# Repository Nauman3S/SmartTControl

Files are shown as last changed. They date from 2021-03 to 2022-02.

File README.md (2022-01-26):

<p align="center">
  <a href="" rel="noopener">
 Project logo</a>
</p>

<h3 align="center">SmartTControl</h3>

<div align="center">

[]()

</div>

---

<p align="center"> SmartTControl ESP32 Firmware and Python based Backend
    <br> 
</p>

## 📝 Table of Contents

- [About](#about)
- [Getting Started](#getting_started)
- [Circuit](#circuit)
- [Server Details](#server)
- [MQTT Topic Details](#mqtt)
- [API Details](#api)
- [Usage](#usage)
- [List Of Components](#list)
- [Built Using](#built_using)
- [Authors](#authors)

## 🧐 About 

This repo contains

- Backend
- Firmware
- Client auto-Installer script
- Detailed instructions

for SmartT Controller.

## Getting Started 

These instructions will get you a copy of the project up and running on your system.

### Prerequisites

Things you need to install the FW.

```
- Arduino IDE
```

### Installing 

A step by step series that tell you how to get the Firmware and Backend running

#### ESP32 Configuration

You should have Arduino IDE Installed

1.  Add ESP32 Board to your Arduino IDE
1.  In your Arduino IDE, go to File> Preferences
    Installing ESP32 Add-on in Arduino IDE Windows, Mac OS X, Linux open preferences
1.  Enter `https://dl.espressif.com/dl/package_esp32_index.json`
    into the “Additional Board Manager URLs” field then, click the “OK” button:
    Note: if you already have the ESP32 boards URL, you can separate the URLs with a comma(each board will go to neaw line) as follows:
    `https://dl.espressif.com/dl/package_esp32_index.json,\n http://arduino.esp8266.com/stable/package_esp8266com_index.json`

1.  Open the Boards Manager. Go to Tools > Board > Boards Manager…
1.  Search for ESP32 and press install button for the ESP32 by Espressif Systems“:
1.  That’s it. It should be installed after a few seconds.
1.  In your Arduino sketchbook directory, create tools directory if it doesn't exist yet.
1.  Unpack the tool into tools directory(present in libs/ESP32FS-1.0.zip) (the path will look like <home_dir>/Arduino/tools/ESP32FS/tool/esp32fs.jar).
1.  Close and re-open the Arduino IDE.

1.  Now copy the contents of the libs folder to the libraries directory of your Arduino
    1. If you are using windows, the libraries directory will be Documents/Arduino/libraries

##### ESP32 Node FW Uploading

1.  Select ESP32 Dev Module from Tools->Board->ESP32
2.  Select the correct port from Tools->Port
3.  Then open Firmware.ino file,
4.  Select Tools > ESP32 Sketch Data Upload menu item. This should start uploading the files into ESP32 flash file system.
5.  Now Upload the Code to your ESP32 Dev Module.
6.  Your ESP32 is now ready to be used.

## Circuit 
### Circuit Diagram

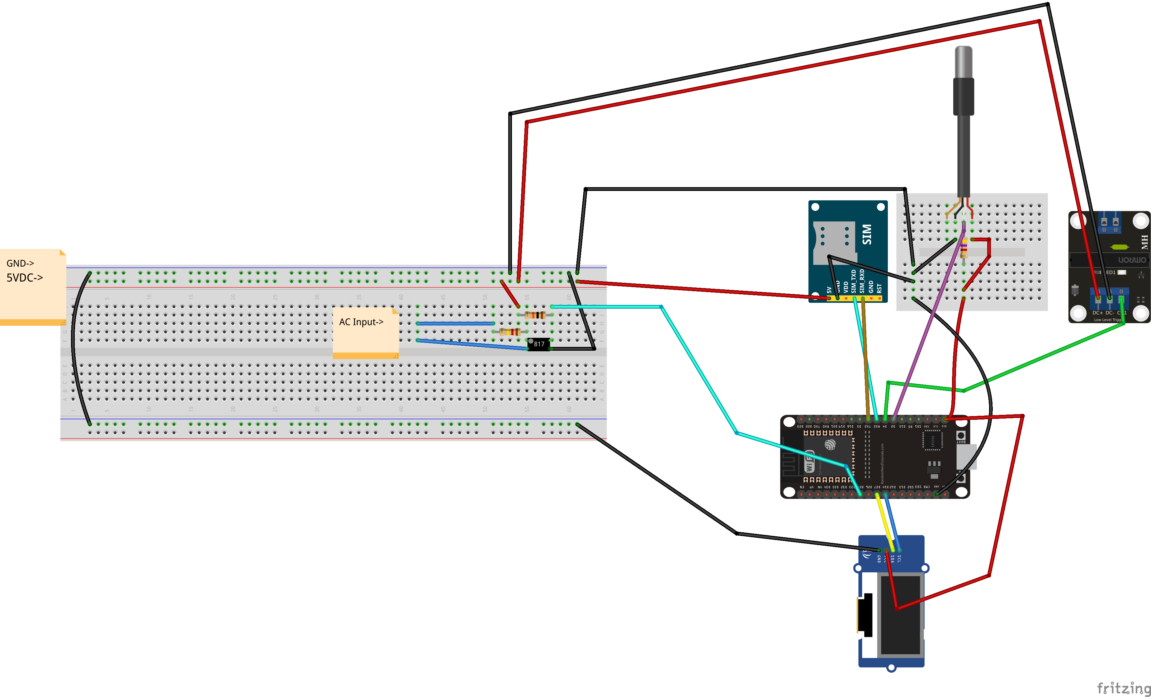
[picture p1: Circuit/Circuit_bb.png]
Circuit


### PCB

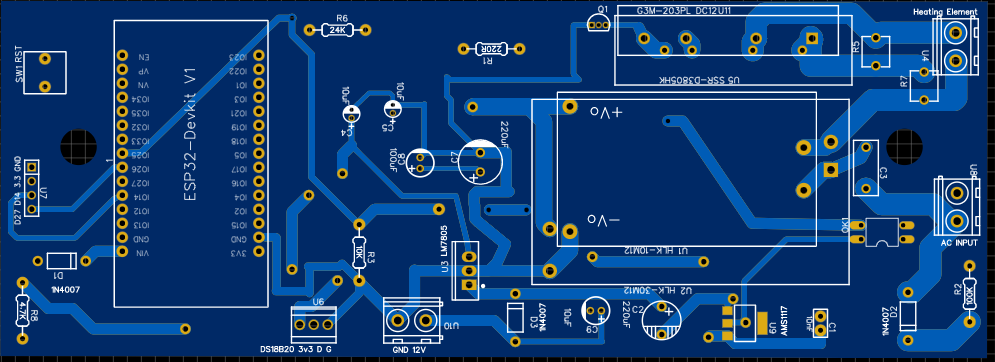
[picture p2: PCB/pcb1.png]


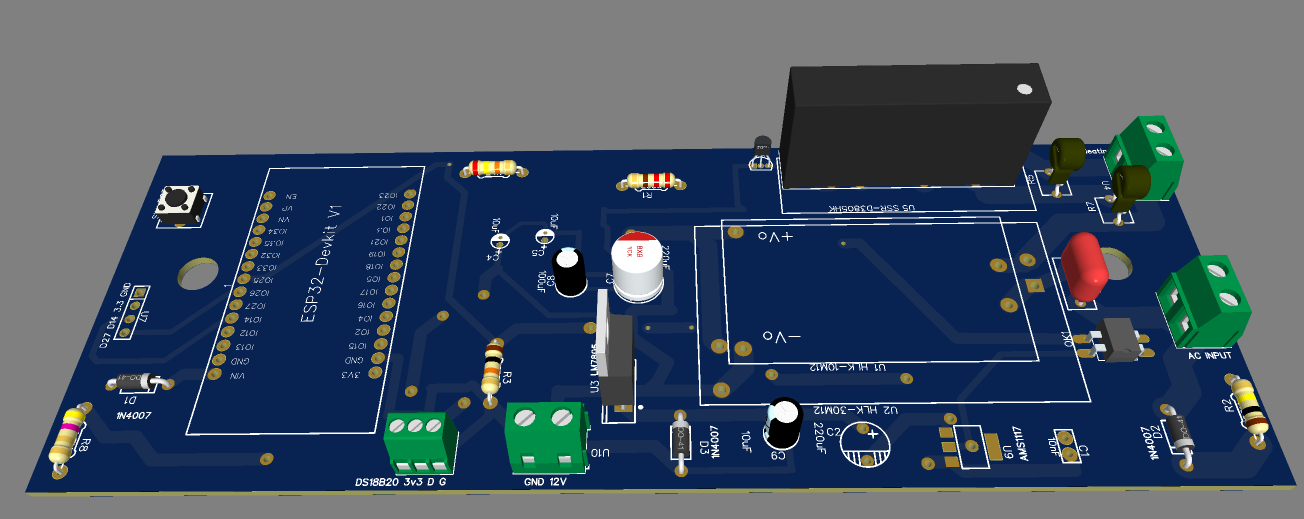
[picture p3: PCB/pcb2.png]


## Server Details 

* This Section was used for WebScrapper based implementation of SmartTControl
### Monitoring

- CapRover

### List of Packages installed on server

- Mosquitto Broker
- NodeJS, NPM, Node, NVM
- PM2
- ufw
- Caprover
- Docker
- mongod
- mongo-express

### Version Details

- Node v12.16.1
- NPM v6.13.4

## API Details 

### Live Sensor Nodes

```http
GET http://cmots.ca:8081/api/checkProductInfo
```

| Parameter | Type | Description |
| :--- | :--- | :--- |
| `imei` | `string` | IMEI of the device |
| `email` | `string` | email address of the cmots account |

-   Returns the data of live sensor in the format below.
```JSON
{
      "status": true,
      "userImeiProductData":
        {
        "Temperature": "15.70",
        "Humidity": "-1000.00",
        "Pressure": "-1000.00",
        "Battery": "-1000.00",
        "ServerTime": "2021-01-06 17:27:24.000"
    }
}
```
### Responses

The CMOTS can return the following responses
- user email not matched  
```javascript
{
    "status": false,
    "message": "User Not Found"
}
```
- device imei not matched  
```javascript
{
"status": false,
"message": "Product Not Found"
}

```

The `message` attribute contains a message commonly used to indicate errors or to return the logged status/

The `status` attribute describes if the transaction was successful or not.

## Usage 

1.  Upload the code to your ESP32.
2. Power on your ESP32, it will present you with an AP named `cmots-abc` (while `cmots` can be changed in the portal and `abc` is a unique id for each esp32)
3. Default captive portal password `12345678` which can be changed in captive portal. 
4. Connect to the ESP32 access point and open the web-browser and navigate to the link `http://cmots.local/_ac`. This link will work on most of the operating systems but if your operating system is not allowing to open it, you may want to check the captive portal IP Address from the serial monitor and can use that IP address inplace of the above mentioned URL. 
5. The default access IP Address is `http://192.168.4.1/_ac` 
6. You will be presented with a main dashboard as shown below(based on your device)
7.  Once connected to a WiFi network, you can again access the captive portal using same URL or the IP Address from the Serial monitor.
8.   You can open settings page with following default credentials
     1.  User: **cmots**
     2.  Password: **admin**

## ⛏️ Built Using 

- [Python](https://www.python.org/) - Backend and Scrapper
- [C++](https://isocpp.org/) - Firmware
- [ESP32-Arduino-Core](https://github.com/espressif/arduino-esp32) - Arduino Core for ESP32
- [Arduino](arduino.cc/) - Arduino Environment

## ✍️ Authors 

- [@Nauman3S](https://github.com/Nauman3S) -  Initial work

<!-- See also the list of [contributors](https://github.com/kylelobo/The-Documentation-Compendium/contributors) who participated in this project.

## 🎉 Acknowledgements 

- Hat tip to anyone whose code was used
- Inspiration
- References -->

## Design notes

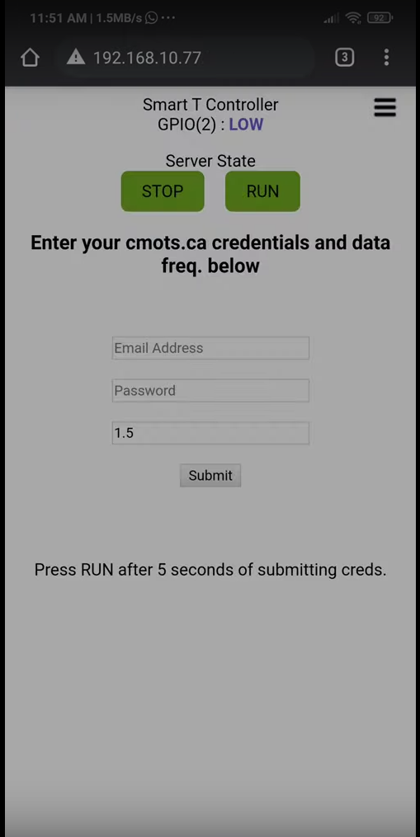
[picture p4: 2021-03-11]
artwork/scr.png

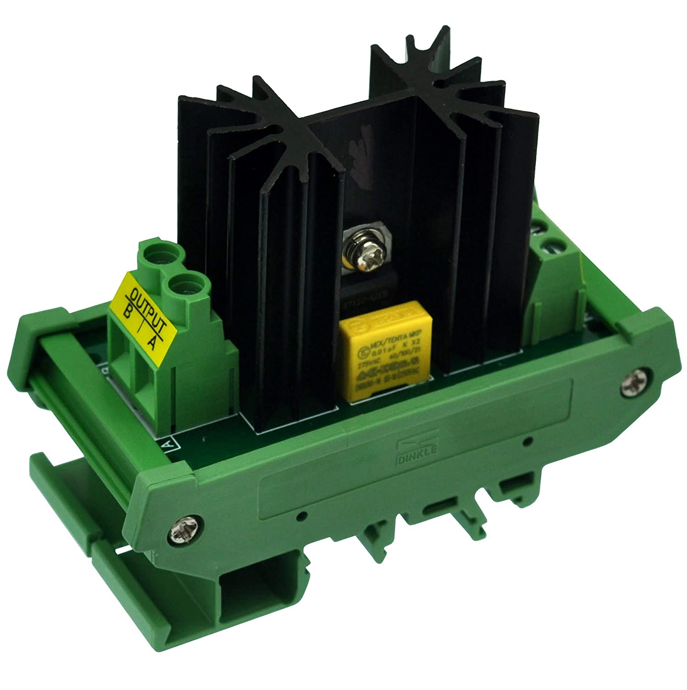
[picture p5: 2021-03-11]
artwork/ssr.jpg

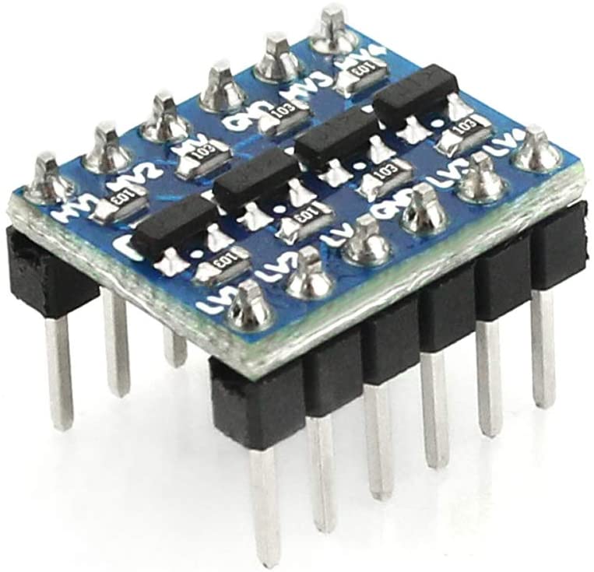
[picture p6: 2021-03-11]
artwork/levelShifter.jpg

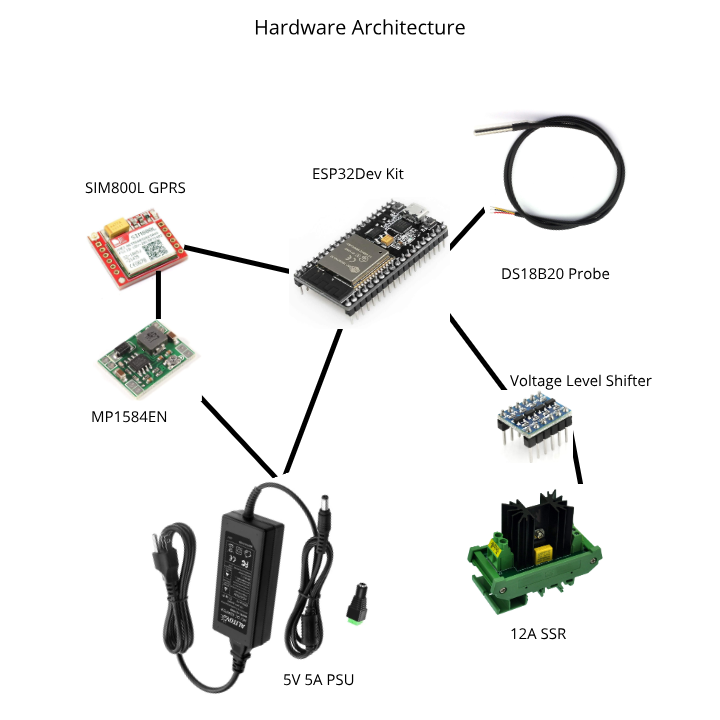
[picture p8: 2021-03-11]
artwork/HWArch.png

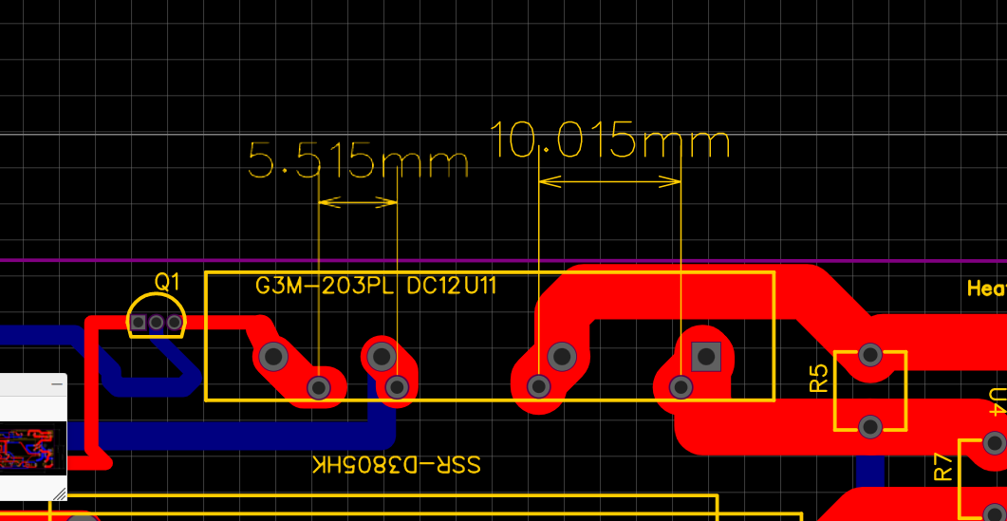
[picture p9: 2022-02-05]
PCB/dims.png

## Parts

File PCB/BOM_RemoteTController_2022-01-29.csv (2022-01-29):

ID | Name | Designator | Footprint | Quantity | Manufacturer Part | Manufacturer | Supplier | Supplier Part | Price | Pins | EasyEDA | JLCPCB Part Class | Contributor | JLCPCB Part Class | Tolerance | Value | Voltage | image | link
1 | ESP32DEVKITV1 | 1 | ESP32-DEVKITV1 | 1 |  |  |  |  |  | 30 |  |  | Baiel Muzuraimov
2 | 10nF | C1 | 10NF | 1 | 103Z-50V | EasyEDA | EasyEDA | E3758 |  | 2 | E3758 |  | erwin.lau |  | -20% | 10nF | 50V
3 | 220uF | C2 | CAP 220UF 16V 5X5 MM. | 1 | 220uF 16V 10*17 | LCSC | LCSC | C43827 | 0.057 | 2 |  |  |  |  |  | 220uF | 16V
4 | 100nF | C3 | CAP-TH_L10.0-W4.5-P7.50-D1.0 | 1 | 104 250v CBBCapacitor | ReliaPro | LCSC | C21820 |  | 2
5 | 10uF | C4,C5 | CAP-D3.0XF1.5 | 2 | 10uF 16V 3*5 | ValuePro | LCSC | C43798 | 0.019 | 2 |  |  |  |  |  | 10uF | 16V
6 | 220uF | C7 | CAP-TH_BD8.0-P3.50-D1.0-FD | 1 | 220uf/35V | ValuePro | LCSC | C2063 | 0.036 | 2 |  |  |  | Extended Part
7 | 100uF | C8 | CAP-TH_BD5.0-P2.00-D0.8-FD | 1 | 100uf/10V | ValuePro | LCSC | C2035 | 0.011 | 2 |  |  |  | Extended Part
8 | 10uF | C9 | CAP-TH_BD5.0-P2.00-D0.8-FD | 1 | 10uF 16V 5*11 | ValuePro | LCSC | C43799 | 0.013 | 2 |  | Extended Part |  | Extended Part
9 | 1N4007RLG | D1,D2,D3 | DO-41_BD2.4-L4.7-P8.70-D0.9-RD | 3 | 1N4007RLG | ON | LCSC | C53568 | 0.064 | 2 |  | Extended Part |  |  |  |  |  | //image.lceda.cn/szlcsc/C53568.jpg
10 | PC817 | OK1 | DIL04 | 1 |  |  |  |  |  | 4 |  |  | abialet
11 | 2N2222A facile for souder | Q1 | 2N2222A | 1 | 2N2222A |  | LCSC |  |  | 3 |  |  | HURARD
12 | 220_R_1/2W | R1 | 220 RESISTOR 1/2W | 1 |  |  |  |  |  | 2 |  |  | jokosays
13 | 100k_R_1/2W | R2 | 100K RESISTOR 1/2W | 1 |  |  |  |  |  | 2 |  |  | jokosays
14 | 10k_R_1/2W | R3 | 10K RESISTOR 1/2W | 1 |  |  |  |  |  | 2 |  |  | jokosays
15 | 101KD05J | R5,R7 | RES-TH_L5.5-W5.0-P5.00-D0.6 | 2 | 101KD05J | Brightking Elec (TAIWAN) | LCSC | C522112 | 0.061 | 2 |  |  | LCSC
16 | 24K_R_1/2W | R6 | 24K RESISTOR 1/2W | 1 |  |  |  |  |  | 2 |  |  | jokosays
17 | 4.7K_R_1/2W | R8 | 4.7 RESISTOR 1/2W | 1 |  |  |  |  |  | 2 |  |  | jokosays
18 | Push Button - 6x6mm - 2 pins | SW1 | PUSH BUTTON | 1 | Push button |  |  |  |  | 2 |  |  | JoseQuintanilla
19 | Hi-Link Power Module | U1 | HLK-10M12 | 1 | HLK-10M12 | HI-LINK | LCSC | C403746 | 5.193 | 4 |  |  | jorgePerez |  |  |  |  |  | https://lcsc.com/product-detail/Power-Modules_HI-LINK-HLK-10M12_C403746.html
20 | HLK-30M12 | U2 | PWRM-TH_HLK-30MXX | 1 | HLK-30M12 | HI-LINK(海凌科) | LCSC | C2761166 | 11.189 | 4 |  | Extended Part | LCSC
21 | LM7805CT | U3 | TO-220-3_L10.0-W4.5-P2.54-L | 1 | LM7805CT | FAIRCHILD | LCSC | C22146 |  | 3
22 | YC0220500000G | U4,U8,U10 | CONN-TH_YC0220500000G | 3 | YC0220500000G | Amphenol | LCSC | C2683165 | 0.646 | 2 |  |  | LCSC
23 | SSR-D3805HK | U5 | SSR-D3805HK | 1 | SSR-D3805HK |  | LCSC | SSR-D3805HK |  | 4 |  |  | Luis Alejandro Hernández Somaza
24 | VN03A1500000G | U6 | CONN-TH_VN03A1500000G | 1 | VN03A1500000G | Amphenol | LCSC | C2683164 | 1.097 | 3 |  |  | LCSC
25 | OLED | U7 | HEADER_PRG_1X04 | 1 |  |  |  |  |  | 4 |  |  | Bert62
26 | AMS1117 | U9 | AMS1117 | 1 |  |  | Amish | HLK-PM01 |  | 3 |  |  | Gremlinware
27 | G3M-203PL DC12 | U11 | RELAY-TH_G3M-203P-DC12 | 1 | G3M-203PL DC12 | OMRON(欧姆龙) | LCSC | C1559423 | 31.848 | 4 |  |  | LCSC

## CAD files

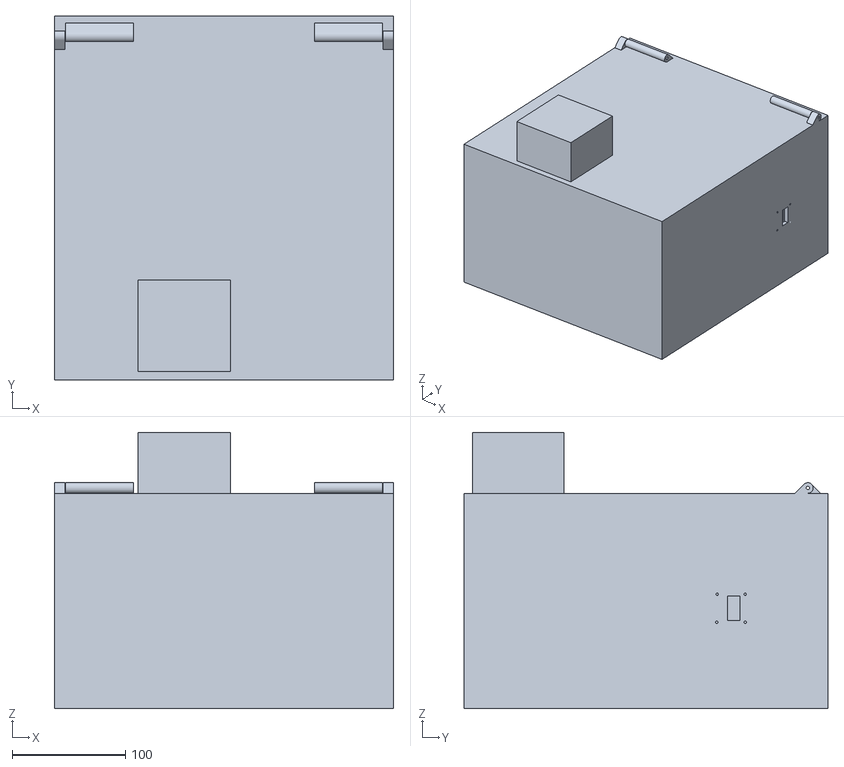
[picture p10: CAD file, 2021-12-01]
Casing/SmartTController v43.stl
300.0 x 321.8 x 244.0

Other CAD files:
Casing/SmartTController v43.f3d

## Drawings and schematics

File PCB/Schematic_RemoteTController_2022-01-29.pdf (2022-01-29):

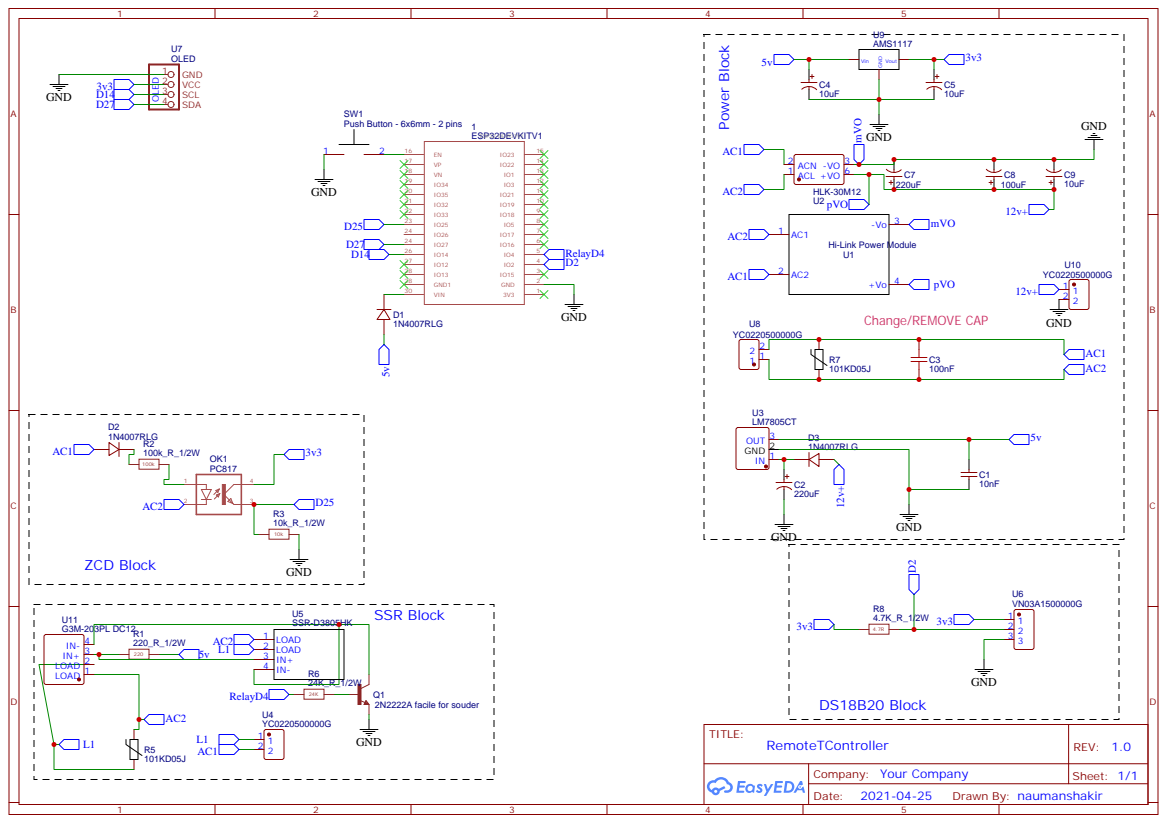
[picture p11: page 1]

Hi-Link Power Module

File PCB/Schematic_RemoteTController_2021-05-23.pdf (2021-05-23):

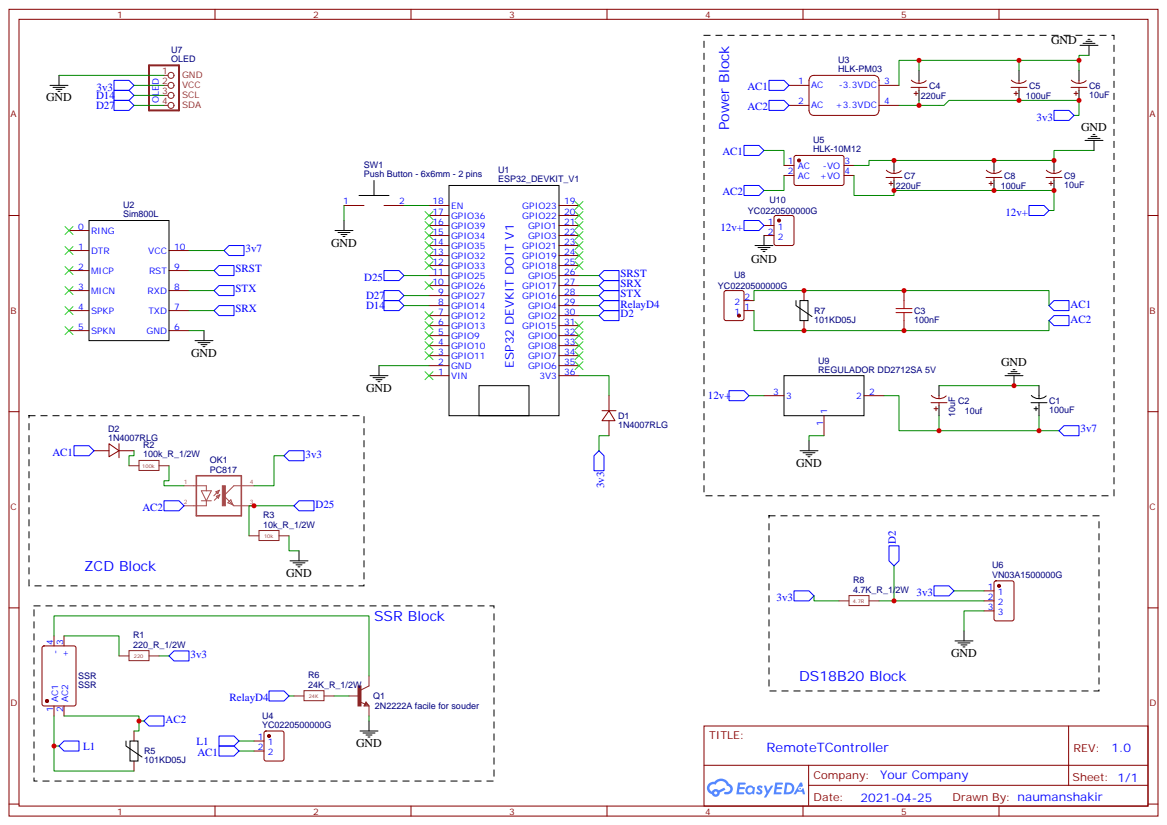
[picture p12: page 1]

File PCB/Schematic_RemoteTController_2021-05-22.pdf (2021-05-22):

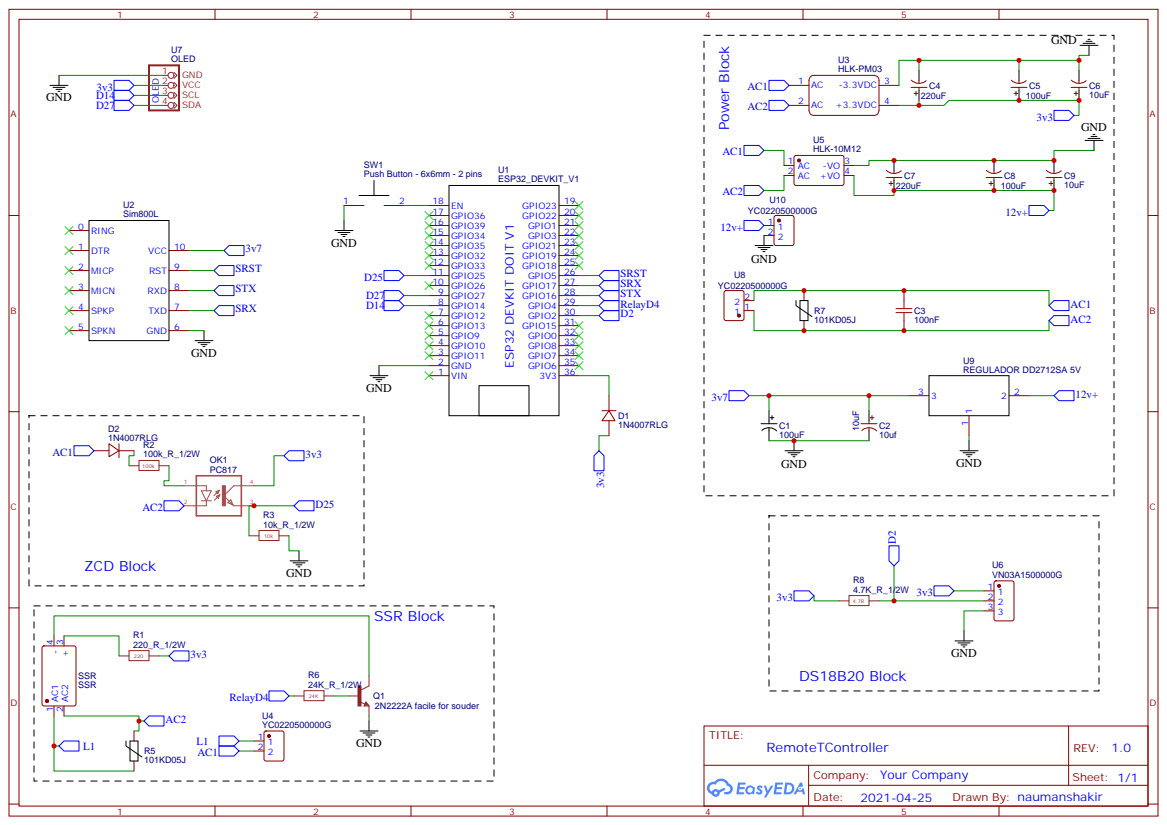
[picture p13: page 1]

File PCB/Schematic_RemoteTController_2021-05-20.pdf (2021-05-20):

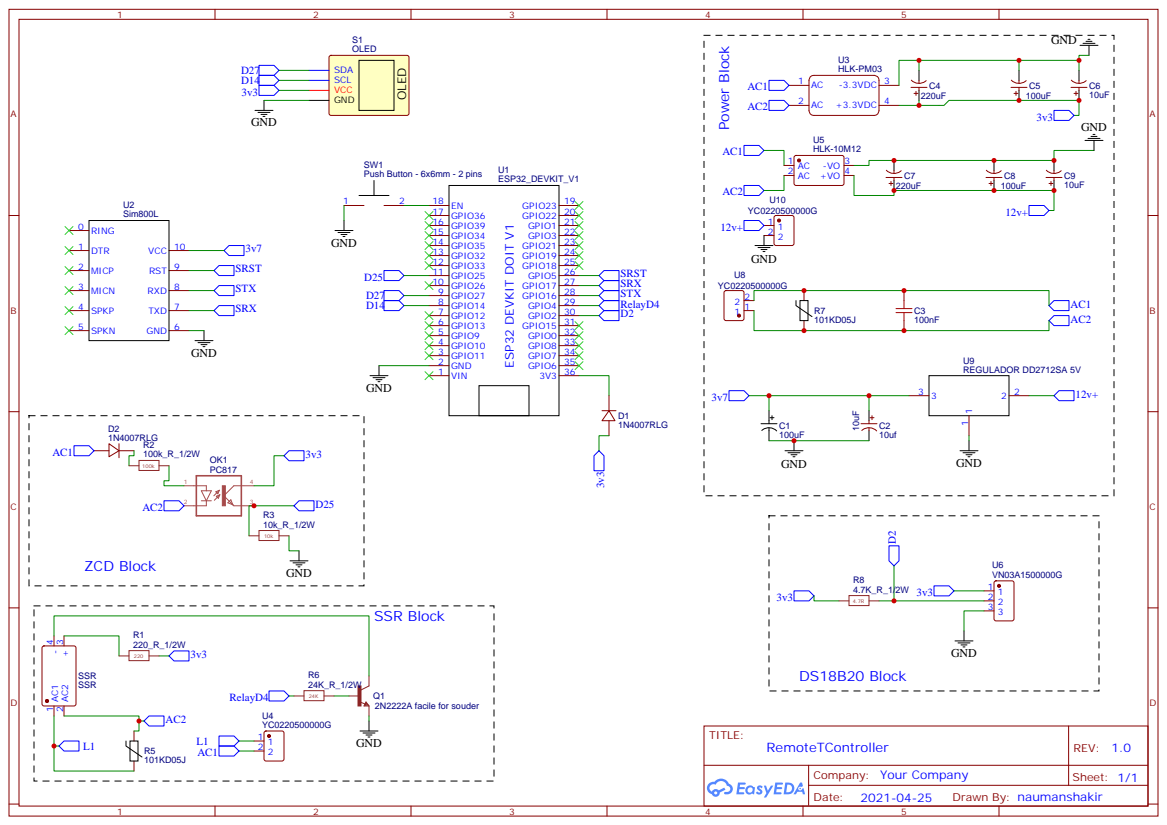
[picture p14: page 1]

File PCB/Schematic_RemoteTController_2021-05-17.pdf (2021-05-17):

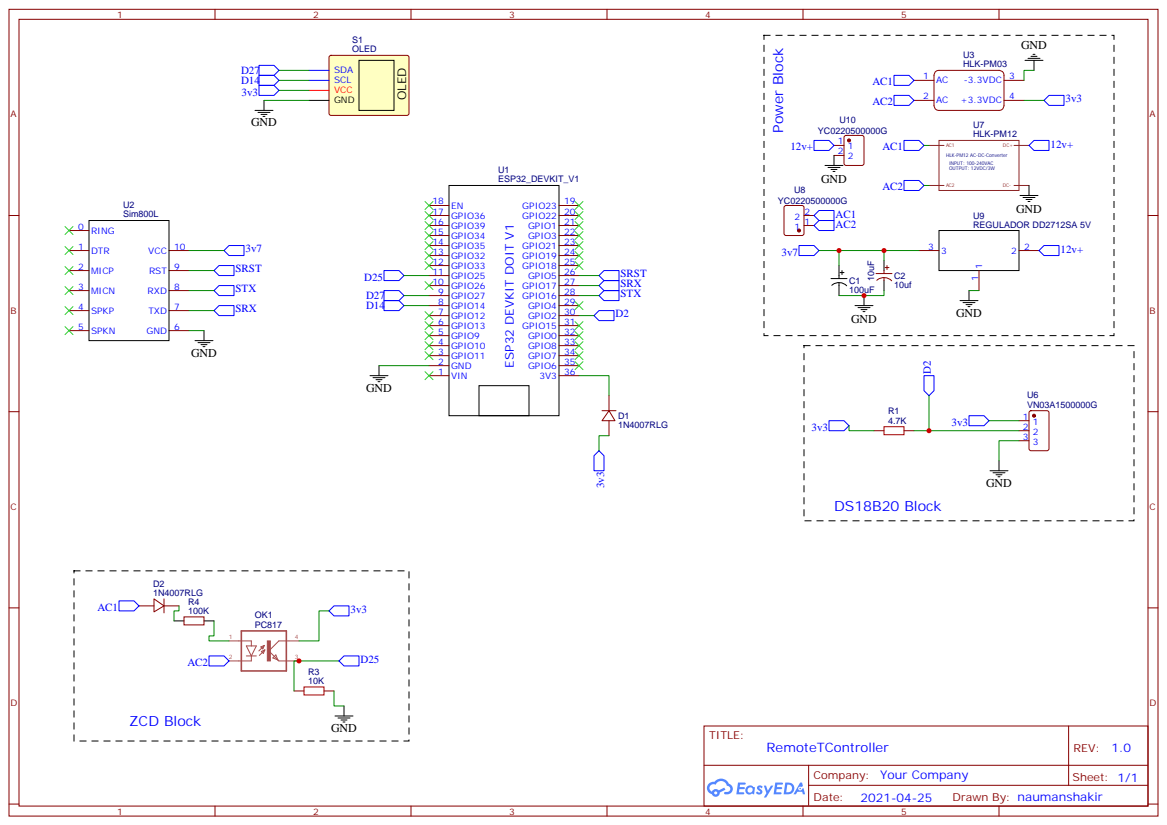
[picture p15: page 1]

HLK-PM12 AC-DC-Converter
INPUT: 100-240VAC
OUTPUT: 12VDC/3W

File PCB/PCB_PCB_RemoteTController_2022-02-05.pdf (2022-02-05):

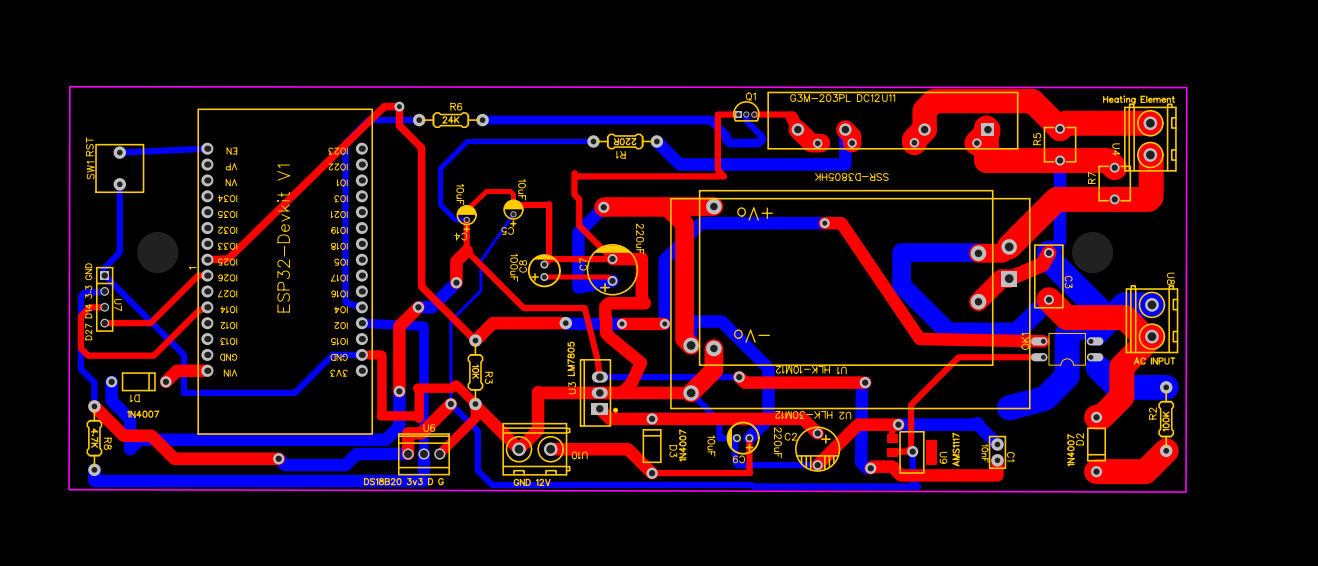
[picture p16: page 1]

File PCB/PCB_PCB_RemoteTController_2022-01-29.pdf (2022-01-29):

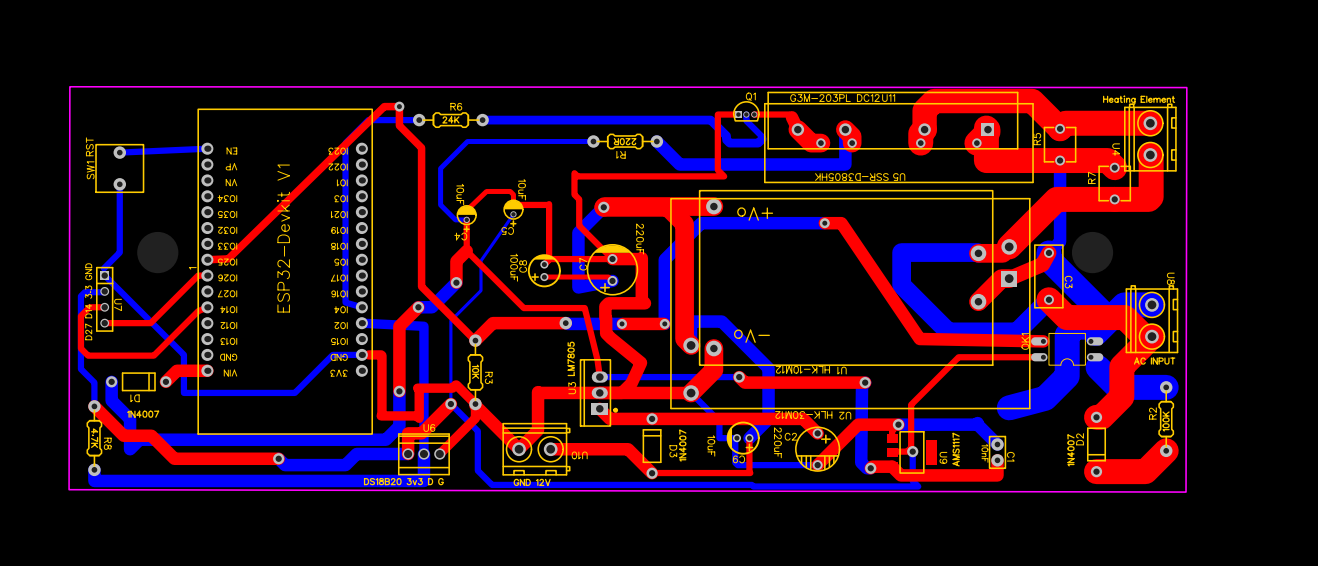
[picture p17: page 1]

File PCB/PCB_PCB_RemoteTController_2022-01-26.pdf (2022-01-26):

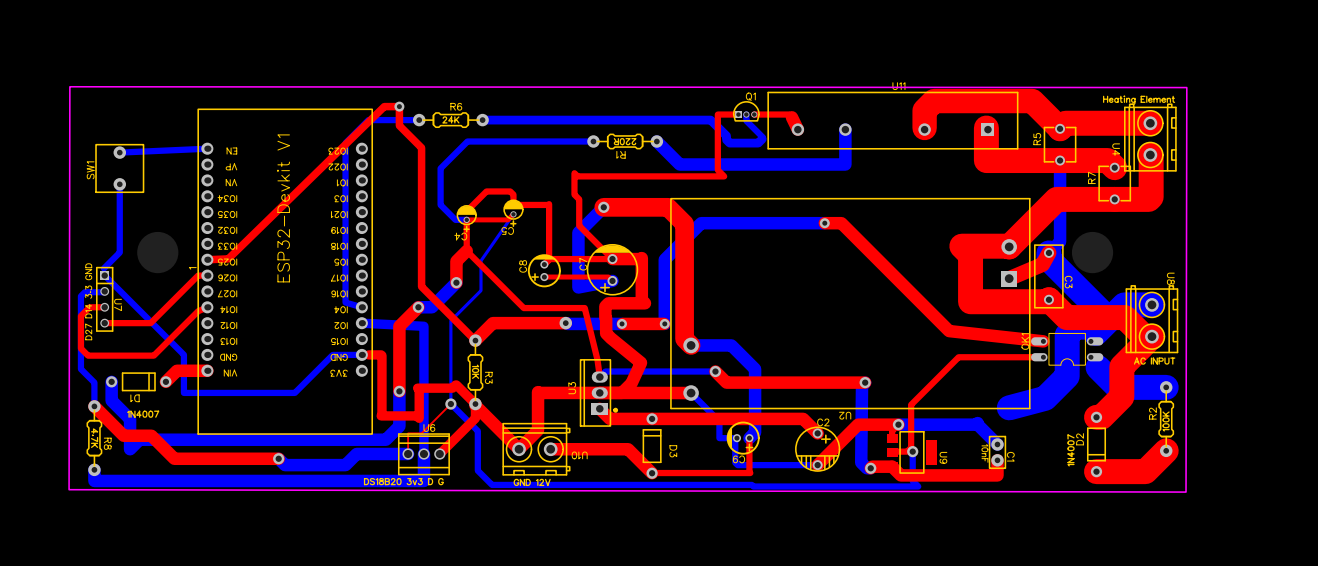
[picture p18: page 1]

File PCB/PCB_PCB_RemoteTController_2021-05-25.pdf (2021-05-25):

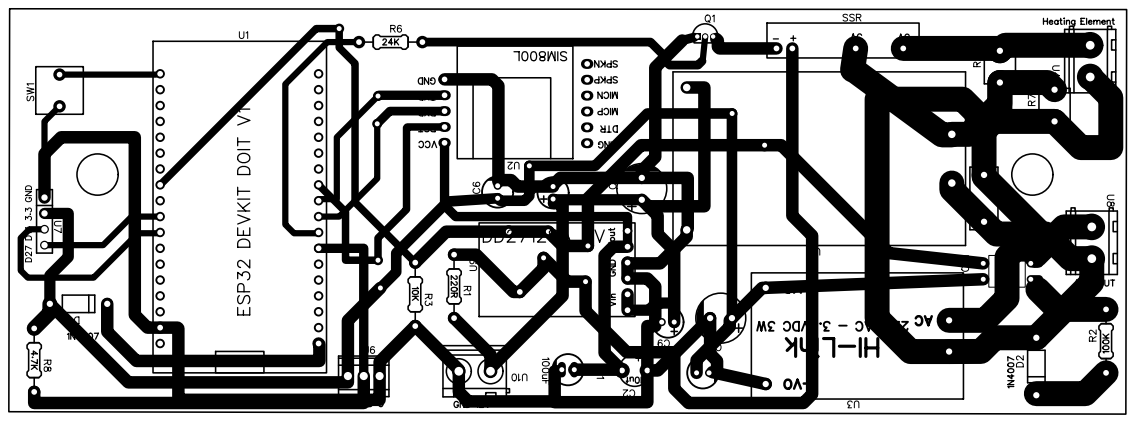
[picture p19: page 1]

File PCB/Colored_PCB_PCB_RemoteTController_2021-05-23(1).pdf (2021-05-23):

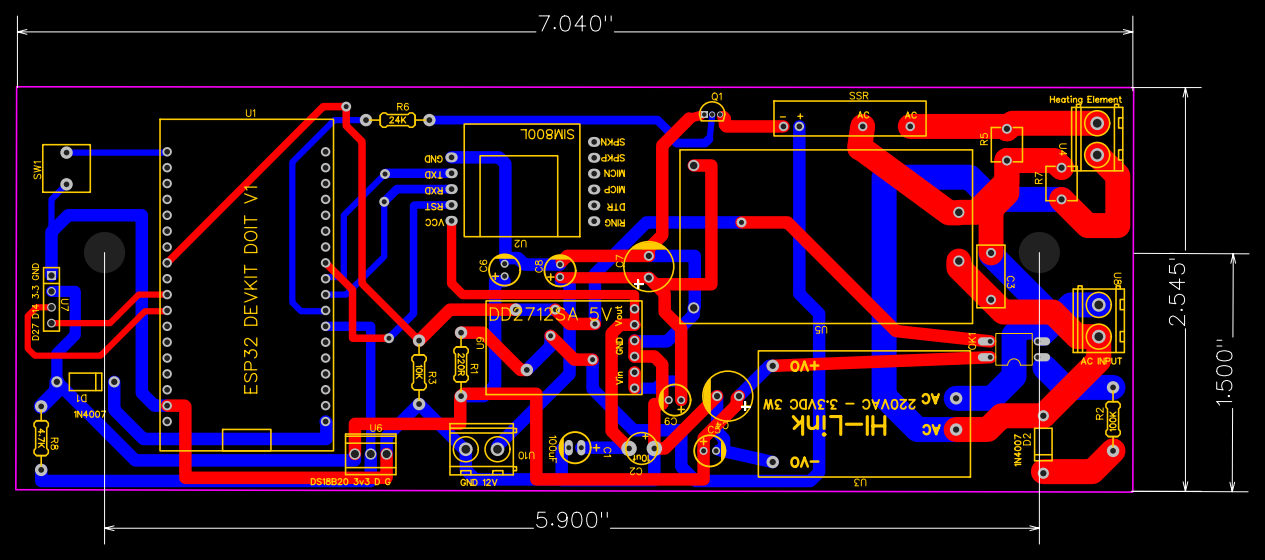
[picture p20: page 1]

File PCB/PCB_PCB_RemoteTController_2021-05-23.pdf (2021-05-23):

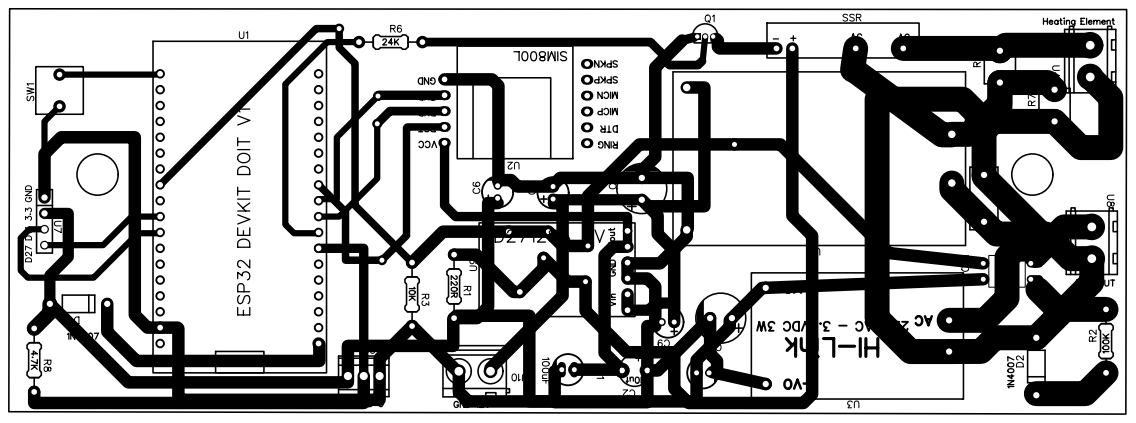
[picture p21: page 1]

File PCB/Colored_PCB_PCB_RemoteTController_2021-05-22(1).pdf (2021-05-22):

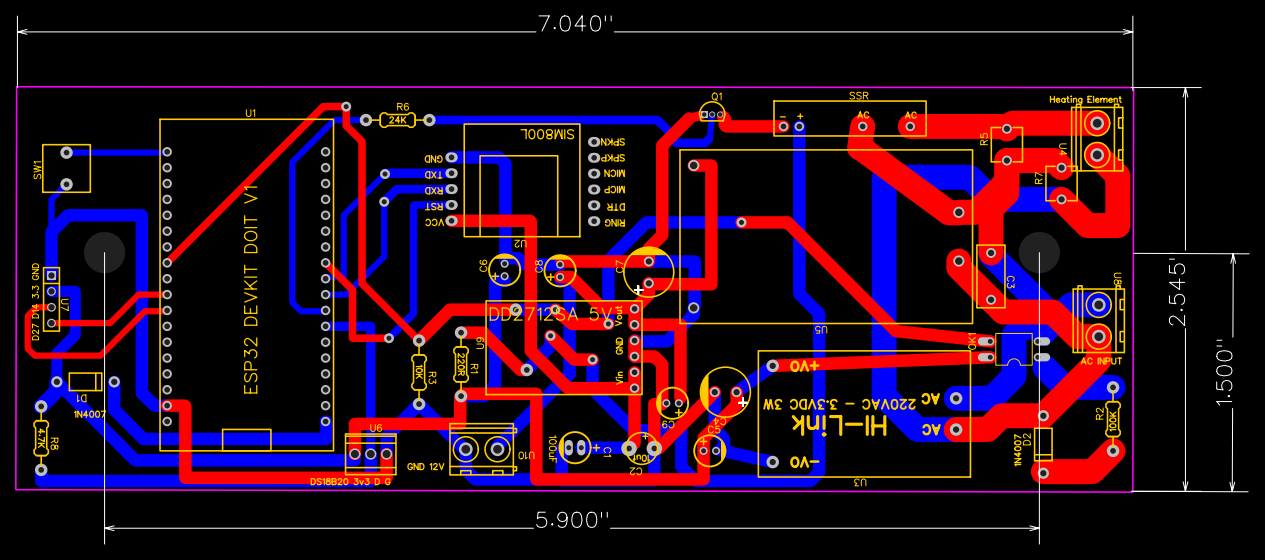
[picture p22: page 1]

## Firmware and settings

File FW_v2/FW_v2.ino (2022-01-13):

#include "headers.h" //all misc. headers and functions
#include "wifiPostReq.h"
#include "webApp.h" //Captive Portal webpages
#include <FS.h>     //ESP32 File System
//CT SB360 to vin pin
IPAddress ipV(192, 168, 4, 1);

TaskHandle_t Task1;
Neotimer n1(2000);
Neotimer n2(3000);
Neotimer n3(5000);
Neotimer n4(7000);
String loadParams(AutoConnectAux &aux, PageArgument &args) //function to load saved settings
{
    (void)(args);
    File param = FlashFS.open(PARAM_FILE, "r");

    if (param)
    {
        Serial.println("load params func");
        aux.loadElement(param);
        Serial.println(param);
        AutoConnectText &networkElm = aux["network"].as<AutoConnectText>();
        AutoConnectText &providerElm = aux["provider"].as<AutoConnectText>();
        AutoConnectText &signalElm = aux["signal"].as<AutoConnectText>();
        AutoConnectText &sensorT = aux["sensorT"].as<AutoConnectText>();
        AutoConnectText &cmotsT = aux["cmotsT"].as<AutoConnectText>();
        AutoConnectText &cmotsHM = aux["cmotsH"].as<AutoConnectText>();
        AutoConnectText &cmotsPM = aux["cmotsP"].as<AutoConnectText>();
        AutoConnectText &cmotsBM = aux["cmotsB"].as<AutoConnectText>();
        AutoConnectText &cmotsSM = aux["cmotsS"].as<AutoConnectText>();

        networkElm.value = String("Network: ") + network;
        // providerElm.value = String("Provider: ") + provider;
        // signalElm.value = String("Signal: ") + signal;
        sensorT.value = String("Sensor Temperature: ") + sensorTemp;
        cmotsT.value = String("cmots Temperature: ") + cmotsTemp;
        cmotsHM.value = String("cmots Humidity: ") + cmotsH;
        cmotsPM.value = String("cmots Pressure: ") + cmotsP;
        cmotsBM.value = String("cmots Battery: ") + cmotsB;
        cmotsSM.value = String("cmots ServerTime: ") + cmotsS;

        // curSValueElm.value="CurS:7788";
        param.close();
    }
    else
        Serial.println(PARAM_FILE " open failed");
    return String("");
}

String saveParams(AutoConnectAux &aux, PageArgument &args) //save the settings
{
    serverName = args.arg("mqttserver"); //broker
    serverName.trim();

    gatewayID = args.arg("gatewayID");
    gatewayID.trim();

    port = args.arg("port"); //user name
    port.trim();

    nodeID = args.arg("nodeID"); //password
    nodeID.trim();

    apPass = args.arg("apPass"); //ap pass
    apPass.trim();

    settingsPass = args.arg("settingsPass"); //ap pass
    settingsPass.trim();

    hostName = args.arg("hostname");
    hostName.trim();

    apn = args.arg("apn");
    apn.trim();
    apnUser = args.arg("apnUser");
    apnUser.trim();
    apnPass = args.arg("apnPass");
    apnPass.trim();

    emailAddress = args.arg("emailAddress");
    emailAddress.trim();
    IMEI = args.arg("IMEI");
    IMEI.trim();

    networkType = args.arg("networkType");
    networkType.trim();

    // The entered value is owned by AutoConnectAux of /mqtt_setting.
    // To retrieve the elements of /mqtt_setting, it is necessary to get
    // the AutoConnectAux object of /mqtt_setting.
    File param = FlashFS.open(PARAM_FILE, "w");
    portal.aux("/mqtt_setting")->saveElement(param, {"mqttserver", "gatewayID", "port", "nodeID", "hostname", "apPass", "settingsPass", "apn", "apnUser", "apnPass", "networkType", "emailAddress", "IMEI"});
    param.close();

    // Echo back saved parameters to AutoConnectAux page.
    AutoConnectText &echo = aux["parameters"].as<AutoConnectText>();
    echo.value = "Server: " + serverName + "<br>";
    echo.value += "Gateway ID: " + gatewayID + "<br>";
    echo.value += "Port: " + port + "<br>";
    echo.value += "Node ID: " + nodeID + "<br>";
    echo.value += "ESP host name: " + hostName + "<br>";
    echo.value += "AP Password: " + apPass + "<br>";
    echo.value += "Settings Page Password: " + settingsPass + "<br>";

    echo.value += "APN: " + apn + "<br>";
    echo.value += "APN Username: " + apnUser + "<br>";
    echo.value += "APN Password: " + apnPass + "<br>";
    echo.value += "Network Type: " + networkType + "<br>";
    echo.value += "CMOTS EMAIL: " + emailAddress + "<br>";
    echo.value += "CMOTS IMEI: " + IMEI + "<br>";

    return String("");
}
bool loadAux(const String auxName) //load defaults from data/*.json
{
    bool rc = false;
    Serial.println("load aux func");
    String fn = auxName + ".json";
    File fs = FlashFS.open(fn.c_str(), "r");
    if (fs)
    {
        rc = portal.load(fs);
        fs.close();
    }
    else
        Serial.println("Filesystem open failed: " + fn);
    return rc;
}

void Task1Loop(void *pvParameters) //GPRS
{
    Serial.print("Task1 running on core ");
    Serial.println(xPortGetCoreID());
    setupGPRS();
    yield();

    for (;;)
    {
        //loopGPRS();
        //capacity = String(getADC(5));
        if (isMQTTConnected())
        {
            yield();
            delay(1000);
        }
    }
}

uint8_t inAP = 0;
unsigned long tmDetection;
const unsigned long scanInterval = 10 * 1000;
uint8_t wifiReconnection()
{
    int16_t ns = WiFi.scanComplete();

    if (ns == WIFI_SCAN_RUNNING)
    {
        // The scan is still running, nothing to do.
    }
    else if (ns == WIFI_SCAN_FAILED)
    {
        // The scan will start in the background where it has not started.
        // But it will wait for scanInterval from the last scan
        if (millis() - tmDetection > scanInterval)
        {
            WiFi.disconnect();
            WiFi.scanNetworks(true, true, false);
        }
    }
    else
    {
        // Now that the scan is finished, you can start checking if any known APs
        // have been detected.
        Serial.printf("scanNetworks:%d\n", ns);

        int16_t scanResult = 0;
        while (scanResult < ns)
        {
            AutoConnectCredential cred;
            station_config_t staConfig;

            if (cred.load(WiFi.SSID(scanResult++).c_str(), &staConfig) >= 0)
            {
                // Successfully detected a known AP, aborting captive portal,
                // Relying on autoReconnect and reconnectInterval to reconnect.
                Serial.printf("AP %s ready\n", (char *)staConfig.ssid);
                WiFi.scanDelete();
                return false;
            }
        }

        Serial.println("No found known AP");
        WiFi.scanDelete();
        tmDetection = millis();
    }

    return true;
}
bool whileCP()
{

    //use this function as a main loop

    ledState(AP_MODE);
    if (n1.repeat())
    {
        //LcdPrint("IP: ", "192.168.4.1");//fixed IP in captive portal

        if (inAP == 0)
        {
            LcdPrint("Status: ", "AP Mode");
            Serial.println("Status: AP Mode");
            inAP = 1;
        }
        else if (inAP == 1)
        {
            LcdPrint("IP: ", "192.168.4.1"); //fixed IP in captive portal
            Serial.println("IP : 192.168.4.1");
            inAP = 0;
        }
    }

    // inAP = 1;

    loopLEDHandler();
    return wifiReconnection();
}

void setup() //main setup functions
{
    Serial.begin(115200);

    xTaskCreatePinnedToCore(
        Task1Loop, /* Task function. */
        "Task1",   /* name of task. */
        10000,     /* Stack size of task */
        NULL,      /* parameter of the task */
        1,         /* priority of the task */
        &Task1,    /* Task handle to keep track of created task */
        1);        /* pin task to core 1 */
    delay(500);

    SetupRelay();
    setupDS18B20();
    setupOLED();
    setupWiFiHTTP();
    setupFreq();
    setupHyst();
    delay(1000);

    if (!MDNS.begin("cmots")) //starting mdns so that user can access webpage using url `esp32.local`(will not work on all devices)
    {
        Serial.println("Error setting up MDNS responder!");
        while (1)
        {
            delay(1000);
        }
    }
#if defined(ARDUINO_ARCH_ESP8266)
    FlashFS.begin();
#elif defined(ARDUINO_ARCH_ESP32)
    FlashFS.begin(true);
#endif
    loadAux(AUX_MQTTSETTING);
    loadAux(AUX_MQTTSAVE);
    AutoConnectAux *setting = portal.aux(AUX_MQTTSETTING);
    if (setting) //get all the settings parameters from setting page on esp32 boot
    {
        Serial.println("Setting loaded");
        PageArgument args;
        AutoConnectAux &mqtt_setting = *setting;
        loadParams(mqtt_setting, args);
        AutoConnectInput &hostnameElm = mqtt_setting["hostname"].as<AutoConnectInput>();
        AutoConnectInput &apPassElm = mqtt_setting["apPass"].as<AutoConnectInput>();
        AutoConnectInput &serverNameElm = mqtt_setting["mqttserver"].as<AutoConnectInput>();
        AutoConnectInput &portElm = mqtt_setting["port"].as<AutoConnectInput>();
        AutoConnectInput &gwIDElm = mqtt_setting["gatewayID"].as<AutoConnectInput>();
        AutoConnectInput &noIDElm = mqtt_setting["nodeID"].as<AutoConnectInput>();
        AutoConnectInput &settingsPassElm = mqtt_setting["settingsPass"].as<AutoConnectInput>();

        AutoConnectInput &apnElm = mqtt_setting["apn"].as<AutoConnectInput>();

        AutoConnectInput &apnUserElm = mqtt_setting["apnUser"].as<AutoConnectInput>();
        AutoConnectInput &apnPassElm = mqtt_setting["apnPass"].as<AutoConnectInput>();
        AutoConnectInput &emailAddressElm = mqtt_setting["emailAddress"].as<AutoConnectInput>();
        AutoConnectInput &IMEIElm = mqtt_setting["IMEI"].as<AutoConnectInput>();

        AutoConnectRadio &networkTypeElm = mqtt_setting["networkType"].as<AutoConnectRadio>();

        AutoConnectText &networkElm = mqtt_setting["network"].as<AutoConnectText>();
        // AutoConnectText &providerElm = mqtt_setting["provider"].as<AutoConnectText>();
        // AutoConnectText &signalElm = mqtt_setting["signal"].as<AutoConnectText>();

        AutoConnectText &sensorTElm = mqtt_setting["sensorT"].as<AutoConnectText>();
        AutoConnectText &cmotsTElm = mqtt_setting["cmotsT"].as<AutoConnectText>();
        //vibSValueElm.value="VibS:11";
        serverName = String(serverNameElm.value);
        port = String(portElm.value);
        gatewayID = String(gwIDElm.value);
        nodeID = String(noIDElm.value);
        hostName = String(hostnameElm.value);
        apPass = String(apPassElm.value);
        settingsPass = String(settingsPassElm.value);
        apnUser = String(apnUserElm.value);
        apnPass = String(apnPassElm.value);
        apn = String(apnElm.value);

        emailAddress = String(emailAddressElm.value);
        IMEI = String(IMEIElm.value);

        networkType = String(networkTypeElm.value());

        if (hostnameElm.value.length())
        {
            //hostName=hostName+ String("-") + String(GET_CHIPID(), HEX);
            //;
            //portal.config(hostName.c_str(), apPass.c_str());
            // portal.config(hostName.c_str(), "123456789AP");
            config.apid = hostName + "-" + String(GET_CHIPID(), HEX);
            config.password = apPass;
            config.psk = apPass;
            // portal.config(hostName.c_str(), "123456789AP");
            Serial.println("(from hostELM) hostname set to " + hostName);
        }
        else
        {

            // hostName = String("OEE");;
            // portal.config(hostName.c_str(), "123456789AP");
            config.apid = hostName + "-" + String(GET_CHIPID(), HEX);
            config.password = apPass;
            config.psk = apPass;
            //config.hostName = hostName;//hostnameElm.value+ "-" + String(GET_CHIPID(), HEX);
            // portal.config(hostName.c_str(), "123456789AP");
            Serial.println("hostname set to " + hostName);
        }
        config.homeUri = "/_ac";
        config.apip = ipV;

        portal.on(AUX_MQTTSETTING, loadParams);
        portal.on(AUX_MQTTSAVE, saveParams);
    }
    else
    {
        Serial.println("aux. load error");
    }
    //config.homeUri = "/_ac";
    config.apip = ipV;
    config.autoReconnect = true;
    config.reconnectInterval = 1;
    Serial.print("AP: ");
    Serial.println(hostName);
    Serial.print("Password: ");
    Serial.println(apPass);
    config.title = "Smart SmartTemperatureController Device"; //set title of webapp

    //add different tabs on homepage
    portal.append("/Test", "Test");
    server.on("/Test", testHandler);
    server.on("/", handleRoot);
    server.on("/relayHandler", relayHandler);
    // Starts user web site included the AutoConnect portal.

    // config.auth = AC_AUTH_DIGEST;
    // config.authScope = AC_AUTHSCOPE_PARTIAL;
    // config.username = hostName;
    // config.password = settingsPass;
    config.autoReconnect = true;  // Attempt automatic reconnection.
    config.reconnectInterval = 3; // Seek interval time is 180[s].

    portal.config(config);
    portal.whileCaptivePortal(whileCP);
    portal.onDetect(atDetect);
    // portal.load(FPSTR(PAGE_AUTH));

    // portal.disableMenu(AC_MENUITEM_DISCONNECT);
    // portal.disableMenu(AC_MENUITEM_OPENSSIDS);
    // portal.disableMenu(AC_MENUITEM_CONFIGNEW);
    if (portal.begin())
    {
        Serial.println("Started, IP:" + WiFi.localIP().toString());
        LcdPrint("IP: ", WiFi.localIP().toString());
        ledState(AP_MODE);
    }
    else
    {
        Serial.println("Connection failed.");
        while (true)
        {
            yield();
            delay(100);
        }
    }

    MDNS.addService("http", "tcp", 80);
    mqttConnect(); //start mqtt
}
int lcdPage = 0;
void loop()
{
    //don't edit this function
    //use whileCP function above as a main loop
    server.handleClient();

    portal.handleRequest();
    loopZCD();
    loopHyst();

    if (n2.repeat()) //publish data to mqtt server
    {
        if (lcdPage == 0)
        {
            ledState(ACTIVE_MODE);
            LcdPrint("Status: ", "Active/STA");
            Serial.println("Status: Active/STA");
            lcdPage++;
        }
        else if (lcdPage == 1)
        {
            LcdPrint("SensorTemp: ", getTempStr());
            Serial.print("SensorTemp: ");
            Serial.println(getTempStr());
            lcdPage++;
        }
        else if (lcdPage == 2)
        {
            postReq();
            LcdPrint("CmotsTemp: ", TempL);
            Serial.print("CmotsTemp: ");
            Serial.println(TempL);
            lcdPage++;
        }
        else if (lcdPage == 3)
        {

            LcdPrint("SetPoint: ", String(getSetPoint()));
            Serial.print("SetPoint: ");
            Serial.println(String(getSetPoint()));
            lcdPage++;
        }
        else if (lcdPage == 4)
        {

            LcdPrint("IP: ", WiFi.localIP().toString());
            Serial.print("IP: ");
            Serial.println(WiFi.localIP().toString());
            lcdPage++;
        }
        else if (lcdPage == 5)
        {

            LcdPrint("Address: ", "http://cmots.local");
            Serial.println("Address: http://cmots.local");
            lcdPage = 0;
        }
    }
    // if (n1.repeat())
    // {
    //     LcdPrint("SesnorTemp: ", getTempStr());
    // }
    // if (n3.repeat())
    // {
    //     postReq();
    //     LcdPrint("CmotsTemp: ", TempL);
    //     // Serial.println(getFrequency());
    // }
    // if (n4.repeat())
    // {
    //     LcdPrint("SetPoint: ", String(getSetPoint()));
    // }
}

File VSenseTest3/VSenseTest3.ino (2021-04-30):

const int Analog_channel_pin= 15;//Potentiometer Pin

int ADC_VALUE = 0;
int voltage_value = 0; 

#include "consts_Headers.h"



void setup() {
  delay(1000);
  Serial.begin(115200);
  Serial.println();
  setupFreq();
  SetupRelay();
 // setupDS18B20();
  
  setupPID();
  
  
  pinMode(BUILTIN_LED, OUTPUT);


  
   
}

void loop() {
 
  loopPID();
 
  loopZCD();
  
 Serial .print('Frequency : ');
 Serial.println(frequency);


  
}

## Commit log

2021-03-12 added master kill switch in backend
2021-03-17 added oled and pid
2021-03-26 dynamic imei selection with buttons
2021-03-26 firmware now using preprocessor directives for zcd and WiFi/GPRS switch
2021-03-29 firmware updated; zcd handling working correctly; user can select wifi or gprs at the time of code upload
    [zcdHandler.h]
2021-03-29 added breadboard based circuit diagram
    [Circuit.fzz, Opto-Isolator2.fzz, esp32.fzz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]
2021-04-09 AC power control test
2021-04-30 added PCB
    [BOM_RemoteTController_2021-04-30.csv, Circuit.fzz, PickAndPlace_PCB_RemoteTController_2021-04-30.csv]
2021-05-17 updated PCB
    [BOM_RemoteTController_2021-04-30.csv, BOM_RemoteTController_2021-05-17.csv, PickAndPlace_PCB_RemoteTController_2021-04-30.csv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]
2021-05-17 Updated pcb pictures
    Updated pcb renders
2021-05-19 Updated PCB(Changelog) -3 Filtering Caps added at the output of 12VDC Module -3 Filtering Caps added at the output of 3.3VDC Module -1 HighVoltage Cap added at AC input -1 MOV added at AC input -220o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
2021-05-20 updated PCB with properly positioned holes
    [BOM_PCB_RemoteTController_2021-05-20.csv, BOM_RemoteTController_2021-05-20.csv, PickAndPlace_PCB_RemoteTController_2021-05-19.csv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]
2021-05-22 updated PCB; repositioned the ESP32 to allow clear space for hole
    [BOM_PCB_RemoteTController_2021-05-20.csv, BOM_PCB_RemoteTController_2021-05-22.csv, BOM_RemoteTController_2021-05-20.csv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]
2021-05-23 updated PCB; pinout of 12v-3v7 module corrected
    [BOM_PCB_RemoteTController_2021-05-22.csv, BOM_PCB_RemoteTController_2021-05-23.csv, BOM_RemoteTController_2021-05-23.csv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]
2021-05-25 updated PCB; tied + of SSR with 12v instead of 3v3
    [BOM_PCB_RemoteTController_2021-05-23.csv, BOM_PCB_RemoteTController_2021-05-25.csv, BOM_RemoteTController_2021-05-23.csv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]
2021-06-29 added working gprs hot switch
2021-12-01 added PID
2021-12-01 added casing files
    [SmartTController v43.f3d, SmartTController v43.stl]
2022-01-13 replaced pidcontroller to hysteresis; oled print fixes
    [FW_v2.ino, PIDController.h]
2022-01-29 added pcb design files
    [BOM_RemoteTController_2022-01-29.csv, PickAndPlace_PCB_RemoteTController_2022-01-29.csv]
